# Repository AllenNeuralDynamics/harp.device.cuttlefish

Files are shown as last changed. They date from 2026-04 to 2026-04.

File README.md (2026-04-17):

An 8-channel TTL input-or-output device with programmable square wave output

## Features
* 8x TTL input or output, configurable.
* Direct PC control of IO Pins:
  * set pins configured as output to either HIGH (5V) or LOW (0V)
  * read the state of pins configured as inputs as either HIGH (~5V) or LOW (~0V) at TTL logic levels.
* Programmable square wave generation with many configurable settings:
  * PWM Frequency range: from 0.01Hz to 2KHz
  * Duty Cycle
  * Offset
  * number of pulses (or infinite)
* Input Capture. Configure pins as inputs to detect
  * rising edges (up to 500Hz)
  * falling edges (up to 500Hz)
  * both! (up to 500hz)
* Harp-protocol compliant (serial num: 0x057B).
* Bonus: "passthrough buffer mode." External 3.3V and 5V CMOS devices can use this device as an octal buffer with external pins.

> [!NOTE]
> This board produces digital outputs and measures digital inputs only! For producing high fidelity _analog_ outputs, refer to the [harp.device.quac](https://github.com/AllenNeuralDynamics/harp.device.quad-dac) device.

## Extra Features
* 6-24VDC input (2.1 x 5.5mm barrel jack, positive center)
* reverse polarity protection
* soft start
* isolated USB to avoid forming ground loops with the PC.

## PWM Waveform Setup
Each IO pin is capable of producing a PWM output. Here are the settings available:
* _offset_us_: how long (in microseconds) the output should remain LOW before switching the output HIGH in one period.
* _on_duration_us_: how long (in microseconds) the output should remain HIGH in one period.
* _off_duration_us_: how long (in microseconds) the output should remain LOW in one period.
* _cycles_: how many pulses to produce or zero for infinite pulses until disabled.
* _invert_: whether the output should be inverted (on-time refers to the output being LOW instead).

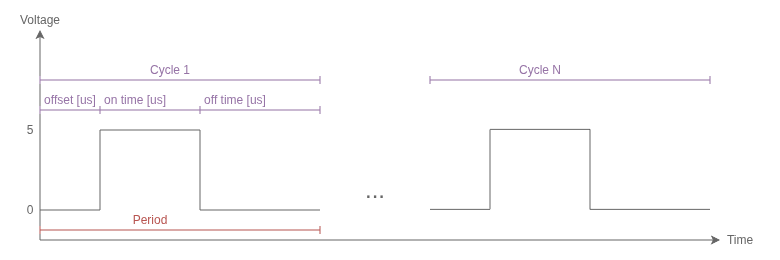
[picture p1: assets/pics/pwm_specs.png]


> [!NOTE]
> Although multiple PWM channels can be set to different settings and produce outputs concurrently, all PWM outputs must be started at the same time.

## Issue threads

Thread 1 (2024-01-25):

Consider alternate scheduling approaches

Poofjunior, 2024-01-25:
As implemented, this setup relies on timing from the Pico's alarm-based timer interrupt, called through the SDK's high-level interface. Currently, this implementation should be fine for frequencies up to 2 KHz but starts to show jitter around 50us.

Alternate approaches to alarm-based interrupts may include:
* using the second core
* using a DMA to PIO scheme where the PIO counts down to the next gpio action
* putting tight code in RAM.

Poofjunior, 2024-01-25:
Other insights:
* Fetching code (function calls) from flash has significant overhead. But it looks like running the ISR from ram has significant benefits ([link](https://forums.raspberrypi.com/viewtopic.php?t=338088))
* It may be possible to move the entire object to ram with `__not_in_flash()` ([link](https://forums.raspberrypi.com/viewtopic.php?t=321002))
* or just move the whole program to ram at the start. ([link](https://forums.raspberrypi.com/viewtopic.php?t=300974))

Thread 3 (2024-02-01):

Move scheduler to core1

Poofjunior, 2024-02-01:
With a tight update loop, we can create waveforms that update every 10 microseconds. But juggling Harp tasks slows down the main loop just enough that we can only update every 100 microseconds or so.

Putting the main loop on its own core and configuring it by sending pwm task parameters through a queue solves this problem.

Poofjunior, 2024-02-01:
done.

Closed 2024-02-01.

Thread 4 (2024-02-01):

Consume an additional alarm

Poofjunior, 2024-02-01:
We have an edge case where we are near an inexact beat frequency where the schedule can't be updated fast enough because two task state changes happen to closely in time. (This is not an issue for exact simultaneous events since we deliberately handle that case.)

The solution would be to be able to call update twice in advance before this inexact "beat frequency" event happened. This would require consuming another alarm to schedule another gpio port state event.

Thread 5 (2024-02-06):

Consider FixedPoint implementation

Poofjunior, 2024-02-06:
The current version of AccelStepper assumes floating point data types, whereas the [primary source](https://www.embedded.com/generate-stepper-motor-speed-profiles-in-real-time/) for this algorithm uses a FixedPoint implementation.

One modest optimization to speed up the main loop would be to rewrite the step computation loop to use FixedPoint in the range of speeds that we want.

* [Fixed Point data type  Reference](https://people.ece.cornell.edu/land/courses/ece4760/PIC32/index_fixed_point.html)

Closed 2024-02-13.

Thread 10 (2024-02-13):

SW Trigger should trigger the schedule immediately

Poofjunior, 2024-02-13:
After the device receives a software trigger command, there is a 1[ms] delay before the schedule starts.

This is an implementation quirk related to how scheduled times are computed. Fixing it would require local PWMTasks to track their interval rather than their absolute scheduled time.

Poofjunior, 2024-08-30:
Fixed in main.
Schedule is now pre-sorted on arrival, which saves the time needed to sort when issuing a software start such that we can start immediately.

Closed 2024-08-30.

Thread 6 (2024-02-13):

Detect if device is in passthrough mode

Poofjunior, 2024-02-13:
The schematic dedicates a GPIO pin to indicate whether the TTL connections are in passthrough mode (i.e: controlled by the external pins) or software mode (i.e: controlled by Harp).

We need to be able to detect the external state of the board and indicate it via a Harp register or event.

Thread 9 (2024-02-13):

Schedule should have the option of referencing Harp Time

Poofjunior, 2024-02-13:
Currently, the schedule computes future task changes based on the local time. It would be valuable to configure the schedule to run off of Harp time instead of local time if we care more about periodic events happening on a synchronized global time reference rather than intervals. (i.e: absolute times more important than relative times). This feature would also guarantee that multiple cuTTLfish boards could trigger synchronously in a way where they never drift from each other.

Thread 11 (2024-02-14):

Device should throw an error if it cannot satisfy schedule

Poofjunior, 2024-02-14:
Currently, core1 locks up when we cannot satisfy the current schedule timing. Instead, we should throw an error detectable by harp

We could implement this as a "weak" friend function in the cpp file that we can override in core1_main.

Poofjunior, 2024-02-15:
This is now implemented as a weak function that can be overwritten elsewhere.

https://github.com/AllenNeuralDynamics/harp.device.cuttlefish/blob/main/firmware/src/pwm_scheduler.cpp#L130

Custom implementation in main:
https://github.com/AllenNeuralDynamics/harp.device.cuttlefish/blob/main/firmware/src/core1_main.cpp#L16

Closed 2024-02-15.

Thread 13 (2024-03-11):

Desired Register Set

Poofjunior, 2024-03-11:
````c++
#pragma pack(push, 1)
struct app_regs_t
{
    volatile uint8_t port_dir; // 1 = output; 0 = input.
    volatile uint8_t port_raw; // current gpio state. Readable and writeable.
    volatile uint8_t pwm_task[sizeof(pwm_task_specs_t)]; // {offset_us (U32),
                                                         //  start_time_us (U32),
                                                         //  stop_time_us (U32),
                                                         //  port_mask (U8),
                                                         //  cycles (U32),
                                                         //  invert (U8)}
                                                         // This register reads
                                                         // all zeros.
    volatile uint8_t arm_ext_trigger; // which port pins (configured as
                                      // inputs) cause the schedule to
                                      // trigger.
                                      // Arm a hardware trigger.
                                      // [0] = 1: TTL pin 0 starts the trigger.
                                      // [1] = 1: TTL pin 1 starts the trigger.
    volatile uint8_t ext_trigger_edge; // value of the gpio pin(s) that cause
                                       // the schedule to start. Example:
                                       // [0]: set external TTL pin 0 trigger
                                       //      type to rising edge (1) or
                                       //      falling edge (0).
                                       // [1]: set external TTL pin 1 trigger
                                       //      type to rising edge (1) or
                                       //      falling edge (0).
                                       // ...
                                       // Resets to rising edge.
    volatile uint8_t arm_ext_untrigger; //
    volatile uint8_t ext_untrigger_edge;  //
    volatile uint8_t sw_trigger;    // Writing nonzero value to this register
                                    // starts the schedule.
    volatile uint8_t sw_untrigger;
    volatile uint8_t schedule_ctrl; // Apply/read various settings. Reads as 0.
                                    // [0] : Stop and clear all configured
                                    //       pwm_tasks.
                                    // [1] : dump 1 event message per configured
                                    //       pwm task from the pwm_task register
                                    //       followed by a
                                    //       write message from this register.
                                    // [4:7]: number of configured tasks.
    // More app "registers" here.
};
#pragma pack(pop)

````

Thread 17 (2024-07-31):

`PortState` change event not implemented

bruno-f-cruz, 2024-07-31:
An Event should be emitted from the `PortState` register each time any of the lines changes. This doesn't seem to be currently implemented.

bruno-f-cruz, 2024-07-31:
After a few more tests it seems the state of the register is not even reflecting the state of the port if I continuously poll from it using periodic read messages.

Poofjunior, 2024-08-08:
Ok, the behavior of `port_state` is to send back an `EVENT` message whenever the state of the pins specified as *inputs* changes state.

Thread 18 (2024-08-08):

Fix Ext/USB IO silkscreen

Poofjunior, 2024-08-08:
**EXT I/O** and **USB I/O** silkscreen values are flipped.

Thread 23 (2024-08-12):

Consider Error Status Register

Poofjunior, 2024-08-12:
Some user-initiated actions will be prevented by `WRITE_ERROR`s, but it is still useful to capture the "status" or "error state" in a separate register for aspects of the device state that can persist or happen.

Example *status* bits:
* `SCHEDULE_IS_RUNNING`
* `DEVICE_IN_EXTERNAL_IO_MODE`

Example *error status* bits:
* `SCHEDULE_FAILED_WHILE_RUNNING`
* `DEVICE_IN_EXTERNAL_IO_MODE`

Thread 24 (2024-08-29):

Disabling Task Should Kill Port Output

Poofjunior, 2024-08-29:
Currently, disabling the task leaves the GPIO pins in their current state, which may be outputting a 1.

Upon disabling the task, we should either:
* reset these pins to inputs
* disable the output

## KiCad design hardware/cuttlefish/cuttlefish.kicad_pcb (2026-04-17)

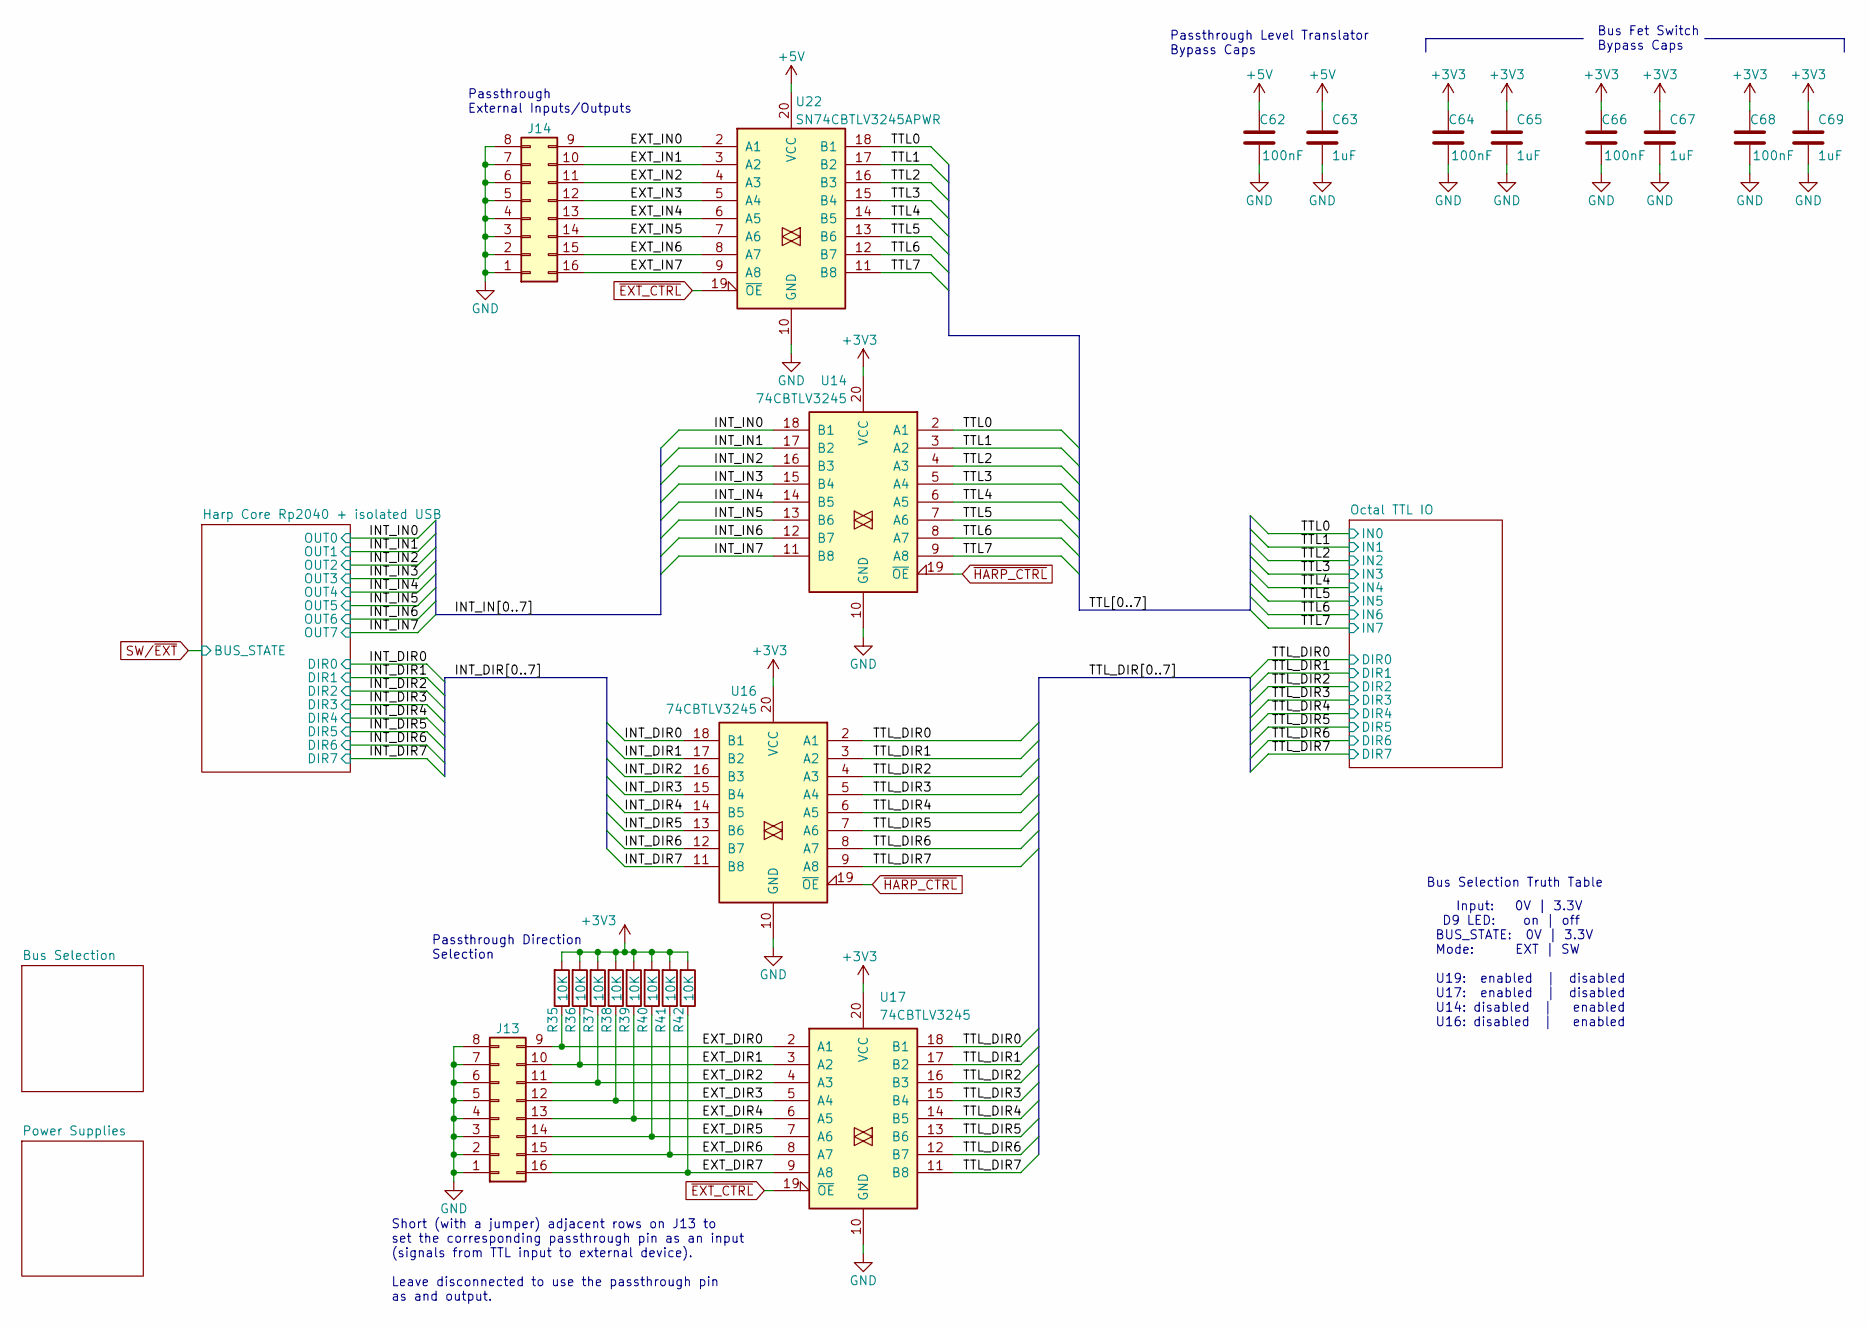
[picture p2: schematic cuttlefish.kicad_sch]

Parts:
C62, C64, C66, C68: 100nF; C_0402_1005Metric; Rated Voltage 50V; Tolerance 10%
C63, C65, C67, C69: 1uF; C_0402_1005Metric; Rated Voltage 35V
J13, J14: Conn_02x08_Counter_Clockwise; PinHeader_2x08_P2.54mm_Horizontal_SMD
R35, R36, R37, R38, R39, R40, R41, R42: 10K; R_0402_1005Metric
U14, U16, U17: 74CBTLV3245; TSSOP-20_4.4x6.5mm_P0.65mm
U22: SN74CBTLV3245APWR; TSSOP-20_4.4x6.5mm_P0.65mm

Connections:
+3V3: C64.2, C65.1, C66.2, C67.1, C68.2, C69.1, R35.2, R36.2, R37.2, R38.2, R39.2, R40.2, R41.2, R42.2, U14.20 (VCC), U16.20 (VCC), U17.20 (VCC); also elsewhere on the board
+5V: C62.2, C63.1, U22.20 (VCC); also elsewhere on the board
/EXT_DIR0: J13.9, R35.1, U17.2 (A1)
/EXT_DIR1: J13.10, R36.1, U17.3 (A2)
/EXT_DIR2: J13.11, R37.1, U17.4 (A3)
/EXT_DIR3: J13.12, R38.1, U17.5 (A4)
/EXT_DIR4: J13.13, R39.1, U17.6 (A5)
/EXT_DIR5: J13.14, R40.1, U17.7 (A6)
/EXT_DIR6: J13.15, R41.1, U17.8 (A7)
/EXT_DIR7: J13.16, R42.1, U17.9 (A8)
/EXT_IN0: J14.9, U22.2 (A1)
/EXT_IN1: J14.10, U22.3 (A2)
/EXT_IN2: J14.11, U22.4 (A3)
/EXT_IN3: J14.12, U22.5 (A4)
/EXT_IN4: J14.13, U22.6 (A5)
/EXT_IN5: J14.14, U22.7 (A6)
/EXT_IN6: J14.15, U22.8 (A7)
/EXT_IN7: J14.16, U22.9 (A8)
/INT_DIR0: U16.18 (B1); also elsewhere on the board
/INT_DIR1: U16.17 (B2); also elsewhere on the board
/INT_DIR2: U16.16 (B3); also elsewhere on the board
/INT_DIR3: U16.15 (B4); also elsewhere on the board
/INT_DIR4: U16.14 (B5); also elsewhere on the board
/INT_DIR5: U16.13 (B6); also elsewhere on the board
/INT_DIR6: U16.12 (B7); also elsewhere on the board
/INT_DIR7: U16.11 (B8); also elsewhere on the board
/INT_IN0: U14.18 (B1); also elsewhere on the board
/INT_IN1: U14.17 (B2); also elsewhere on the board
/INT_IN2: U14.16 (B3); also elsewhere on the board
/INT_IN3: U14.15 (B4); also elsewhere on the board
/INT_IN4: U14.14 (B5); also elsewhere on the board
/INT_IN5: U14.13 (B6); also elsewhere on the board
/INT_IN6: U14.12 (B7); also elsewhere on the board
/INT_IN7: U14.11 (B8); also elsewhere on the board
/TTL0: U14.2 (A1), U22.18 (B1); also elsewhere on the board
/TTL1: U14.3 (A2), U22.17 (B2); also elsewhere on the board
/TTL2: U14.4 (A3), U22.16 (B3); also elsewhere on the board
/TTL3: U14.5 (A4), U22.15 (B4); also elsewhere on the board
/TTL4: U14.6 (A5), U22.14 (B5); also elsewhere on the board
/TTL5: U14.7 (A6), U22.13 (B6); also elsewhere on the board
/TTL6: U14.8 (A7), U22.12 (B7); also elsewhere on the board
/TTL7: U14.9 (A8), U22.11 (B8); also elsewhere on the board
/TTL_DIR0: U16.2 (A1), U17.18 (B1); also elsewhere on the board
/TTL_DIR1: U16.3 (A2), U17.17 (B2); also elsewhere on the board
/TTL_DIR2: U16.4 (A3), U17.16 (B3); also elsewhere on the board
/TTL_DIR3: U16.5 (A4), U17.15 (B4); also elsewhere on the board
/TTL_DIR4: U16.6 (A5), U17.14 (B5); also elsewhere on the board
/TTL_DIR5: U16.7 (A6), U17.13 (B6); also elsewhere on the board
/TTL_DIR6: U16.8 (A7), U17.12 (B7); also elsewhere on the board
/TTL_DIR7: U16.9 (A8), U17.11 (B8); also elsewhere on the board
GND: C62.1, C63.2, C64.1, C65.2, C66.1, C67.2, C68.1, C69.2, J13.1, J13.2, J13.3, J13.4, J13.5, J13.6, J13.7, J13.8, J14.1, J14.2, J14.3, J14.4, J14.5, J14.6, J14.7, J14.8, U14.10 (GND), U16.10 (GND), U17.10 (GND), U22.10 (GND); also elsewhere on the board
~EXT_CTRL: U17.19 (~OE), U22.19 (~OE); also elsewhere on the board
~HARP_CTRL: U14.19 (~OE), U16.19 (~OE); also elsewhere on the board

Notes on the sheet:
Passthrough External Inputs/Outputs
Input: 0V | 3.3V D9 LED: on | off BUS_STATE: 0V | 3.3V Mode: EXT | SW U19: enabled | disabled U17: enabled | disabled U14: disabled | enabled U16: disabled | enabled
Passthrough Direction Selection
Bus Fet Switch Bypass Caps
Short (with a jumper) adjacent rows on J13 to set the corresponding passthrough pin as an input (signals from TTL input to external device). Leave disconnected to use the passthrough pin as and output.
Passthrough Level Translator Bypass Caps
Bus Selection Truth Table

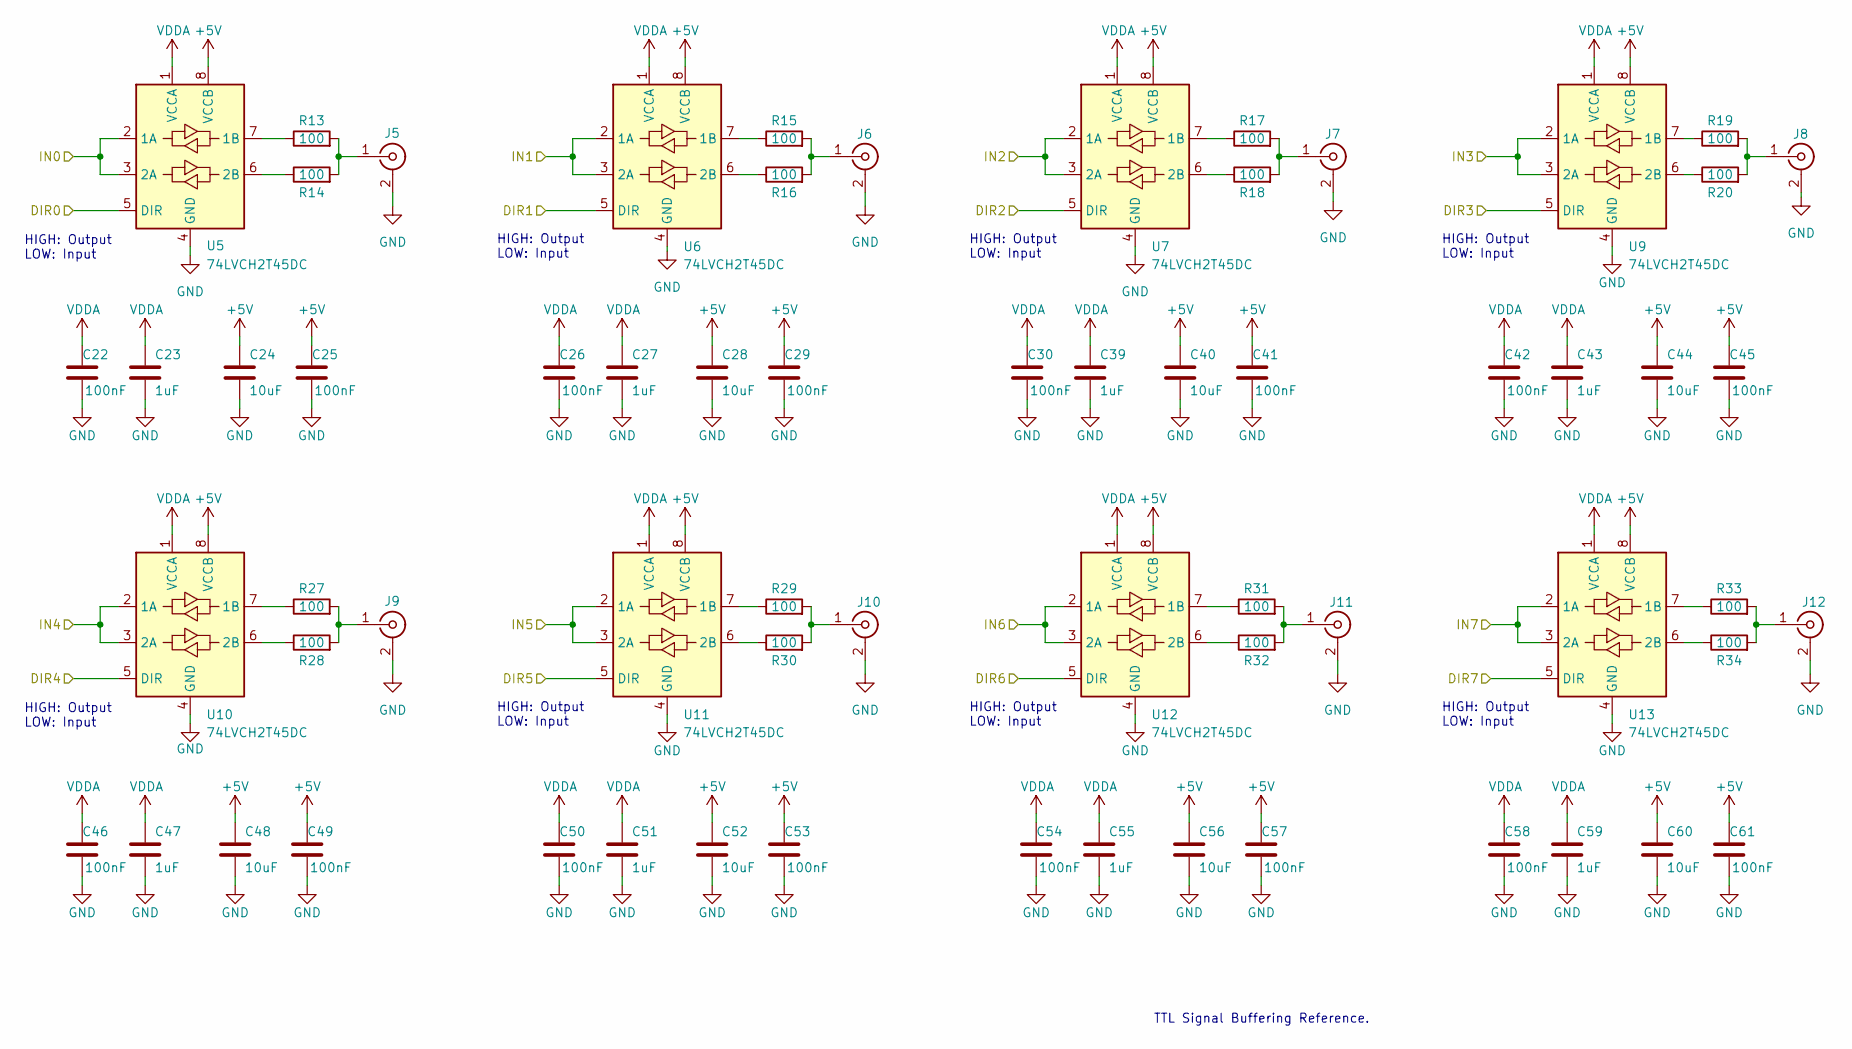
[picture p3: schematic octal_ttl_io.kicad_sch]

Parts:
C22, C25, C26, C29, C30, C41, C42, C45, C46, C49, C50, C53, C54, C57, C58, C61: 100nF; C_0402_1005Metric; Rated Voltage 50V; Tolerance 10%
C23, C27, C39, C43, C47, C51, C55, C59: 1uF; C_0402_1005Metric; Rated Voltage 35V
C24, C28, C40, C44, C48, C52, C56, C60: 10uF; C_0805_2012Metric; Rated Voltage 25V
J5, J6, J7, J8, J9, J10, J11, J12: Conn_Coaxial; BNC_AmphenolRF_031-5329-52RFX_Vertical
R13, R14, R15, R16, R17, R18, R19, R20, R27, R28, R29, R30, R31, R32, R33, R34: 100; R_0402_1005Metric; Tolerance 1%
U5, U6, U7, U9, U10, U11, U12, U13: 74LVCH2T45DC; VSSOP-8_2.3x2mm_P0.5mm_TexasInstruments

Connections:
+5V: C24.1, C25.2, C28.1, C29.2, C40.1, C41.2, C44.1, C45.2, C48.1, C49.2, C52.1, C53.2, C56.1, C57.2, C60.1, C61.2, U5.8 (VCCB), U6.8 (VCCB), U7.8 (VCCB), U9.8 (VCCB), U10.8 (VCCB), U11.8 (VCCB), U12.8 (VCCB), U13.8 (VCCB); also elsewhere on the board
/TTL0: U5.2 (1A), U5.3 (2A); also elsewhere on the board
/TTL1: U6.2 (1A), U6.3 (2A); also elsewhere on the board
/TTL2: U7.2 (1A), U7.3 (2A); also elsewhere on the board
/TTL3: U9.2 (1A), U9.3 (2A); also elsewhere on the board
/TTL4: U10.2 (1A), U10.3 (2A); also elsewhere on the board
/TTL5: U11.2 (1A), U11.3 (2A); also elsewhere on the board
/TTL6: U12.2 (1A), U12.3 (2A); also elsewhere on the board
/TTL7: U13.2 (1A), U13.3 (2A); also elsewhere on the board
/TTL_DIR0: U5.5 (DIR); also elsewhere on the board
/TTL_DIR1: U6.5 (DIR); also elsewhere on the board
/TTL_DIR2: U7.5 (DIR); also elsewhere on the board
/TTL_DIR3: U9.5 (DIR); also elsewhere on the board
/TTL_DIR4: U10.5 (DIR); also elsewhere on the board
/TTL_DIR5: U11.5 (DIR); also elsewhere on the board
/TTL_DIR6: U12.5 (DIR); also elsewhere on the board
/TTL_DIR7: U13.5 (DIR); also elsewhere on the board
GND: C22.1, C23.2, C24.2, C25.1, C26.1, C27.2, C28.2, C29.1, C30.1, C39.2, C40.2, C41.1, C42.1, C43.2, C44.2, C45.1, C46.1, C47.2, C48.2, C49.1, C50.1, C51.2, C52.2, C53.1, C54.1, C55.2, C56.2, C57.1, C58.1, C59.2, C60.2, C61.1, J5.2 (Ext), J6.2 (Ext), J7.2 (Ext), J8.2 (Ext), J9.2 (Ext), J10.2 (Ext), J11.2 (Ext), J12.2 (Ext), U5.4 (GND), U6.4 (GND), U7.4 (GND), U9.4 (GND), U10.4 (GND), U11.4 (GND), U12.4 (GND), U13.4 (GND); also elsewhere on the board
unnamed: J5.1 (In), R13.2, R14.2
unnamed: J6.1 (In), R15.2, R16.2
unnamed: J7.1 (In), R17.2, R18.2
unnamed: J8.1 (In), R19.2, R20.2
unnamed: J9.1 (In), R27.2, R28.2
unnamed: J10.1 (In), R29.2, R30.2
unnamed: J11.1 (In), R31.2, R32.2
unnamed: J12.1 (In), R33.2, R34.2
unnamed: R13.1, U5.7 (1B)
unnamed: R14.1, U5.6 (2B)
unnamed: R15.1, U6.7 (1B)
unnamed: R16.1, U6.6 (2B)
unnamed: R17.1, U7.7 (1B)
unnamed: R18.1, U7.6 (2B)
unnamed: R19.1, U9.7 (1B)
unnamed: R20.1, U9.6 (2B)
unnamed: R27.1, U10.7 (1B)
unnamed: R28.1, U10.6 (2B)
unnamed: R29.1, U11.7 (1B)
unnamed: R30.1, U11.6 (2B)
unnamed: R31.1, U12.7 (1B)
unnamed: R32.1, U12.6 (2B)
unnamed: R33.1, U13.7 (1B)
unnamed: R34.1, U13.6 (2B)
VDDA: C22.2, C23.1, C26.2, C27.1, C30.2, C39.1, C42.2, C43.1, C46.2, C47.1, C50.2, C51.1, C54.2, C55.1, C58.2, C59.1, U5.1 (VCCA), U6.1 (VCCA), U7.1 (VCCA), U9.1 (VCCA), U10.1 (VCCA), U11.1 (VCCA), U12.1 (VCCA), U13.1 (VCCA); also elsewhere on the board

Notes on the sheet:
HIGH: Output LOW: Input
TTL Signal Buffering Reference.

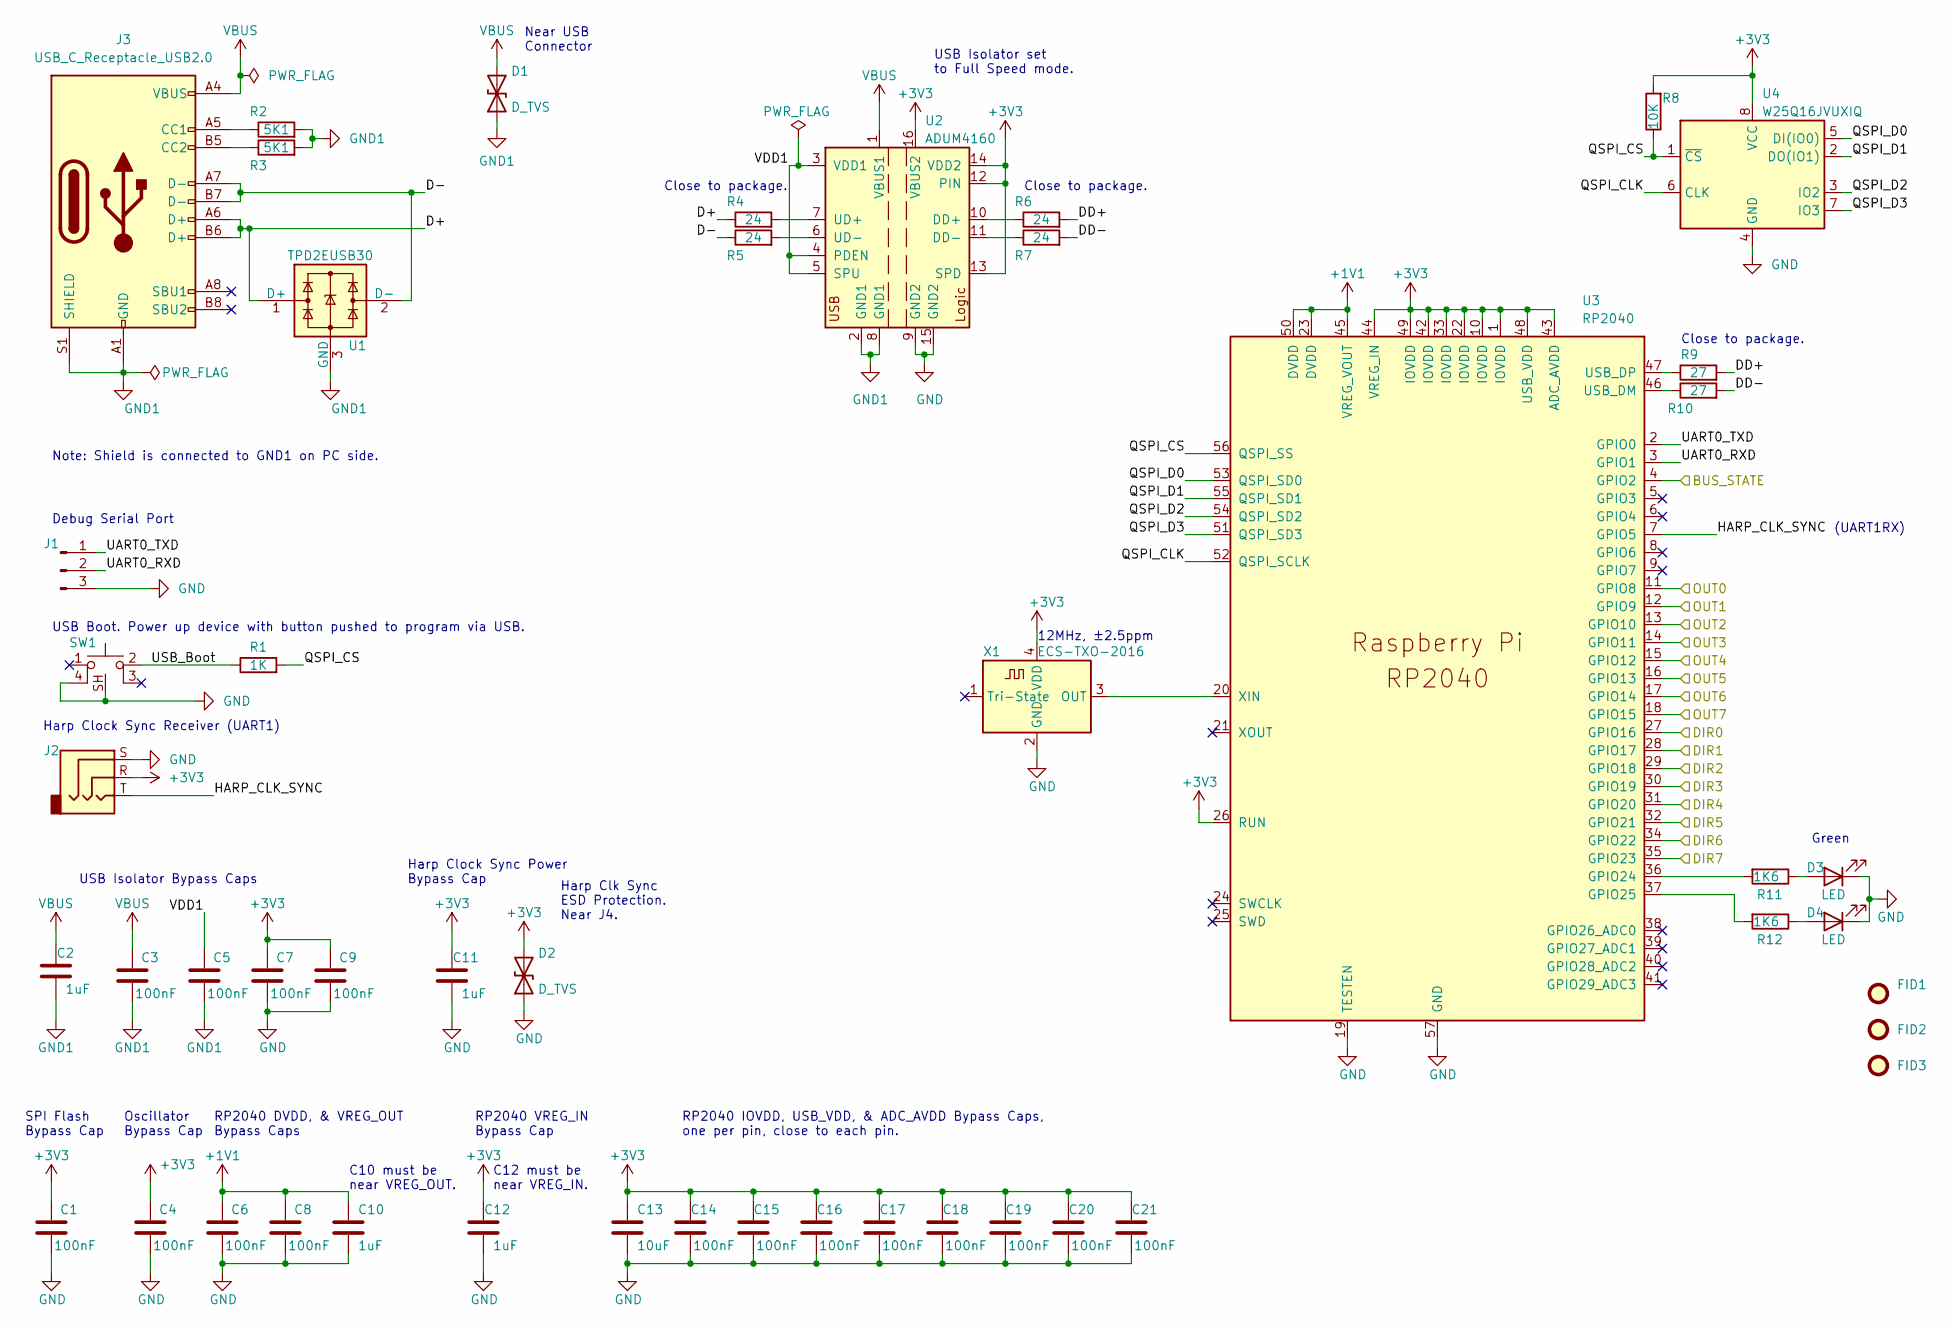
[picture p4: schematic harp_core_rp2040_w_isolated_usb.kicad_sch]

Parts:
C1, C3, C4, C5, C6, C7, C8, C9, C14, C15, C16, C17, C18, C19, C20, C21: 100nF; C_0402_1005Metric; Rated Voltage 50V; Tolerance 10%
C2, C10, C11, C12: 1uF; C_0402_1005Metric; Rated Voltage 35V
C13: 10uF; C_0805_2012Metric; Rated Voltage 25V
D1, D2: D_TVS; D_0402_1005Metric
D3, D4: LED; LED_0603_1608Metric
FID1, FID2, FID3: Fiducial; Fiducial_0.5mm_Mask1mm
J1: Conn_01x03_Male; PinHeader_1x03_P2.54mm_Vertical
J2: AudioJack3; Jack_3.5mm_CUI_SJ-3523-SMT_Horizontal
J3: USB_C_Receptacle_USB2.0; USB_C_Receptacle_JAE_DX07S016JA1R1500
R1: 1K; R_0402_1005Metric; Tolerance 1%
R2, R3: 5K1; R_0402_1005Metric; Tolerance 1%
R4, R5, R6, R7: 24; R_0402_1005Metric; Tolerance 1%
R8: 10K; R_0402_1005Metric
R9, R10: 27; R_0402_1005Metric; Tolerance 1%
R11, R12: 1K6; R_0402_1005Metric
SW1: SW_Push_1P1T-SH_NO_Vertical_Wuerth_WS-TASV
U1: TPD2EUSB30; Texas_DRT-3
U2: ADUM4160; SOIC-16W_7.5x10.3mm_P1.27mm
U3: RP2040; RP2040-QFN-56
U4: W25Q16JVUXIQ; Winbond-8USON-2x3mm
X1: ECS-TXO-2016; Crystal_SMD_2016-4Pin_2.0x1.6mm; Tolerance ±2.5ppm

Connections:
+1V1: C6.2, C8.2, C10.1, U3.23 (DVDD), U3.45 (VREG_VOUT), U3.50 (DVDD)
+3V3: C1.2, C4.2, C7.2, C9.2, C11.1, C12.1, C13.1, C14.2, C15.2, C16.2, C17.2, C18.2, C19.2, C20.2, C21.2, D2.2 (A2), J2.R, R8.2, U2.12 (PIN), U2.13 (SPD), U2.14 (VDD2), U2.16 (VBUS2), U3.1 (IOVDD), U3.10 (IOVDD), U3.22 (IOVDD), U3.26 (RUN), U3.33 (IOVDD), U3.42 (IOVDD), U3.43 (ADC_AVDD), U3.44 (VREG_IN), U3.48 (USB_VDD), U3.49 (IOVDD), U4.8 (VCC), X1.4 (VDD); also elsewhere on the board
/Harp Core Rp2040 + isolated USB/D+: J3.A6 (D+), J3.B6 (D+), R4.1, U1.1 (D+)
/Harp Core Rp2040 + isolated USB/D-: J3.A7 (D-), J3.B7 (D-), R5.1, U1.2 (D-)
/Harp Core Rp2040 + isolated USB/DD+: R6.2, R9.2
/Harp Core Rp2040 + isolated USB/DD-: R7.2, R10.2
/Harp Core Rp2040 + isolated USB/HARP_CLK_SYNC: J2.T, U3.7 (GPIO5)
/Harp Core Rp2040 + isolated USB/QSPI_CLK: U3.52 (QSPI_SCLK), U4.6 (CLK)
/Harp Core Rp2040 + isolated USB/QSPI_CS: R1.2, R8.1, U3.56 (QSPI_SS), U4.1 (~CS)
/Harp Core Rp2040 + isolated USB/QSPI_D0: U3.53 (QSPI_SD0), U4.5 (DI(IO0))
/Harp Core Rp2040 + isolated USB/QSPI_D1: U3.55 (QSPI_SD1), U4.2 (DO(IO1))
/Harp Core Rp2040 + isolated USB/QSPI_D2: U3.54 (QSPI_SD2), U4.3 (IO2)
/Harp Core Rp2040 + isolated USB/QSPI_D3: U3.51 (QSPI_SD3), U4.7 (IO3)
/Harp Core Rp2040 + isolated USB/UART0_RXD: J1.2, U3.3 (GPIO1)
/Harp Core Rp2040 + isolated USB/UART0_TXD: J1.1, U3.2 (GPIO0)
/Harp Core Rp2040 + isolated USB/USB_Boot: R1.1, SW1.2
/Harp Core Rp2040 + isolated USB/VDD1: C5.2, U2.3 (VDD1), U2.4 (PDEN), U2.5 (SPU)
/INT_DIR0: U3.27 (GPIO16); also elsewhere on the board
/INT_DIR1: U3.28 (GPIO17); also elsewhere on the board
/INT_DIR2: U3.29 (GPIO18); also elsewhere on the board
/INT_DIR3: U3.30 (GPIO19); also elsewhere on the board
/INT_DIR4: U3.31 (GPIO20); also elsewhere on the board
/INT_DIR5: U3.32 (GPIO21); also elsewhere on the board
/INT_DIR6: U3.34 (GPIO22); also elsewhere on the board
/INT_DIR7: U3.35 (GPIO23); also elsewhere on the board
/INT_IN0: U3.11 (GPIO8); also elsewhere on the board
/INT_IN1: U3.12 (GPIO9); also elsewhere on the board
/INT_IN2: U3.13 (GPIO10); also elsewhere on the board
/INT_IN3: U3.14 (GPIO11); also elsewhere on the board
/INT_IN4: U3.15 (GPIO12); also elsewhere on the board
/INT_IN5: U3.16 (GPIO13); also elsewhere on the board
/INT_IN6: U3.17 (GPIO14); also elsewhere on the board
/INT_IN7: U3.18 (GPIO15); also elsewhere on the board
GND: C1.1, C4.1, C6.1, C7.1, C8.1, C9.1, C10.2, C11.2, C12.2, C13.2, C14.1, C15.1, C16.1, C17.1, C18.1, C19.1, C20.1, C21.1, D2.1 (A1), D3.1 (K), D4.1 (K), J1.3, J2.S, SW1.4, SW1.SH, U2.9 (GND2), U2.15 (GND2), U3.19 (TESTEN), U3.57 (GND), U4.4 (GND), X1.2 (GND); also elsewhere on the board
GND1: C2.2, C3.1, C5.1, D1.1 (A1), J3.A1 (GND), J3.A12 (GND), J3.B1 (GND), J3.B12 (GND), J3.S1 (SHIELD), R2.2, R3.2, U1.3 (GND), U2.2 (GND1), U2.8 (GND1)
unnamed: D3.2 (A), R11.1
unnamed: D4.2 (A), R12.1
unnamed: J3.A5 (CC1), R2.1
unnamed: J3.B5 (CC2), R3.1
unnamed: R6.1, U2.10 (DD+)
unnamed: R7.1, U2.11 (DD-)
unnamed: R4.2, U2.7 (UD+)
unnamed: R5.2, U2.6 (UD-)
unnamed: R11.2, U3.36 (GPIO24)
unnamed: R12.2, U3.37 (GPIO25)
unnamed: R10.1, U3.46 (USB_DM)
unnamed: R9.1, U3.47 (USB_DP)
unnamed: U3.20 (XIN), X1.3 (OUT)
SW/~EXT: U3.4 (GPIO2); also elsewhere on the board
VBUS: C2.1, C3.2, D1.2 (A2), J3.A4 (VBUS), J3.A9 (VBUS), J3.B4 (VBUS), J3.B9 (VBUS), U2.1 (VBUS1)

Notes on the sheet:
USB Isolator Bypass Caps
Near USB Connector
Close to package.
Harp Clock Sync Power Bypass Cap
USB Isolator set to Full Speed mode.
12MHz, ±2.5ppm
Debug Serial Port
USB Boot. Power up device with button pushed to program via USB.
(UART1RX)
Harp Clock Sync Receiver (UART1)
Note: Shield is connected to GND1 on PC side.
RP2040 DVDD, & VREG_OUT Bypass Caps
RP2040 IOVDD, USB_VDD, & ADC_AVDD Bypass Caps, one per pin, close to each pin.
C10 must be near VREG_OUT.
RP2040 VREG_IN Bypass Cap
SPI Flash Bypass Cap
Harp Clk Sync ESD Protection. Near J4.
Oscillator Bypass Cap
C12 must be near VREG_IN.
Green

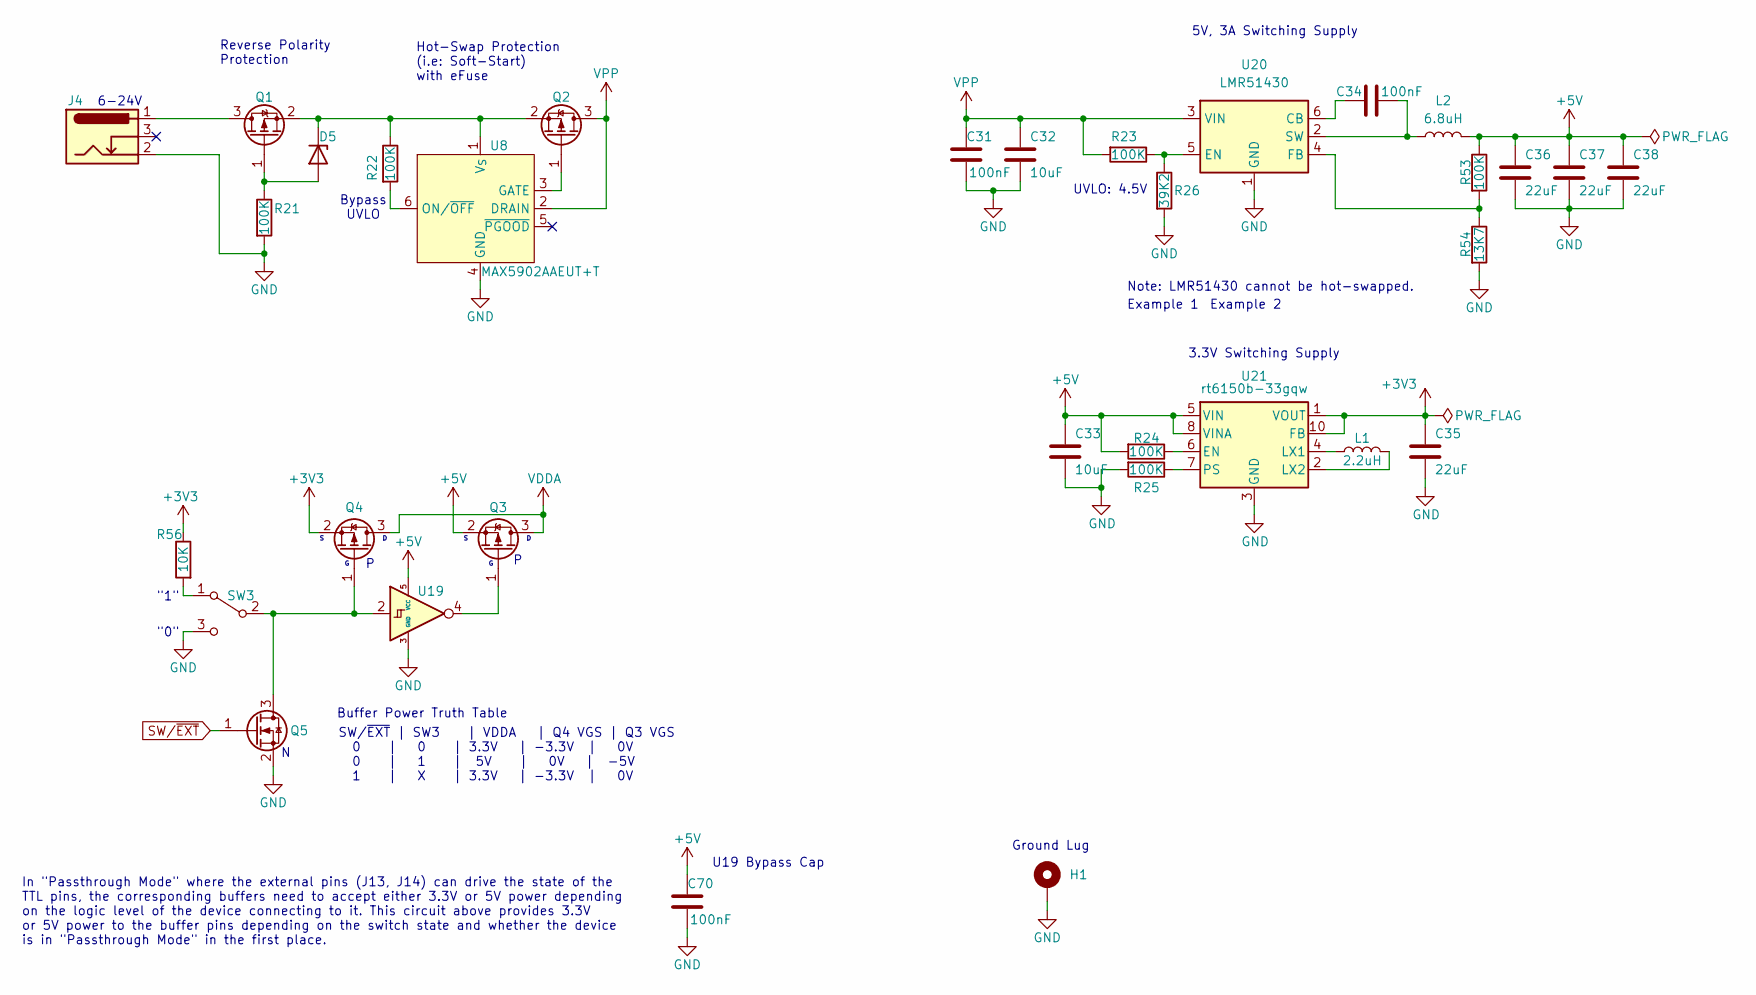
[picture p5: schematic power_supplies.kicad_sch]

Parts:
C31, C34, C70: 100nF; C_0402_1005Metric; Rated Voltage 50V; Tolerance 10%
C32, C33: 10uF; C_0805_2012Metric; Rated Voltage 25V
C35, C36, C37, C38: 22uF; C_0805_2012Metric; Rated Voltage 25V
D5: BZV55B15; D_MiniMELF
H1: MountingHole_Pad; Terminal_Keystone_779x_EdgeMount_Horizontal
J4: Barrel_Jack_Switch; BarrelJack_Same_Sky_PJ-102AH_Horizontal
L1: 2.2uH; L_0603_1608Metric
L2: 6.8uH; L_Bourns-SRP4030FA
Q1, Q2, Q3, Q4: Si2369DS; SOT-23
Q5: DMN2040U; SOT-23
R21, R22, R23, R24, R25, R53: 100K; R_0402_1005Metric; Tolerance 1%
R26: 39K2; R_0402_1005Metric; Tolerance 1%
R54: 13K7; R_0402_1005Metric; Tolerance 1%
R56: 10K; R_0402_1005Metric
SW3: SW_SPDT; SW_SPDT_CK-JS102011SAQN
U8: MAX5902AAEUT+T; SOT-23-6
U19: SN74LVC1G14DRL; SOT-553
U20: LMR51430; SOT-23-6
U21: rt6150b-33gqw; WDFN-10-1EP_2.5x2.5mm_P0.5_EP1.25x2.1mm

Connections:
+3V3: C35.1, Q4.2 (S), R56.1, U21.1 (VOUT), U21.10 (FB); also elsewhere on the board
+5V: C33.1, C36.1, C37.1, C38.1, C70.2, L2.2, Q3.2 (S), R24.2, R53.1, U19.5 (VCC), U21.5 (VIN), U21.8 (VINA); also elsewhere on the board
GND: C31.1, C32.2, C33.2, C35.2, C36.2, C37.2, C38.2, C70.1, H1.1, J4.2, Q5.2 (S), R21.2, R25.2, R26.2, R54.2, SW3.3 (C), U8.4 (GND), U19.3 (GND), U20.1 (GND), U21.3 (GND), U21.9 (GND), U21.11 (GND); also elsewhere on the board
unnamed: D5.2 (A), Q1.1 (G), R21.1
unnamed: D5.1 (K), Q1.2 (S), Q2.2 (S), R22.1, U8.1 (V_{S})
unnamed: J4.1, Q1.3 (D)
unnamed: Q2.1 (G), U8.3 (GATE)
unnamed: Q3.1 (G), U19.4
unnamed: Q4.1 (G), Q5.3 (D), SW3.2 (B), U19.2
unnamed: R56.2, SW3.1 (A)
unnamed: R22.2, U8.6 (ON/~OFF)
unnamed: C34.2, U20.6 (CB)
unnamed: R23.1, R26.1, U20.5 (EN)
unnamed: R53.2, R54.1, U20.4 (FB)
unnamed: C34.1, L2.1, U20.2 (SW)
unnamed: R24.1, U21.6 (EN)
unnamed: L1.1, U21.4 (LX1)
unnamed: L1.2, U21.2 (LX2)
unnamed: R25.1, U21.7 (PS)
SW/~EXT: Q5.1 (G); also elsewhere on the board
VDDA: Q3.3 (D), Q4.3 (D); also elsewhere on the board
VPP: C31.2, C32.1, Q2.3 (D), R23.2, U8.2 (DRAIN), U20.3 (VIN)

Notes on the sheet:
U19 Bypass Cap
Example 2
5V, 3A Switching Supply
"1"
"0"
Example 1
Bypass UVLO
Note: LMR51430 cannot be hot-swapped.
Buffer Power Truth Table
UVLO: 4.5V
Hot-Swap Protection (i.e: Soft-Start) with eFuse
6-24V
In "Passthrough Mode" where the external pins (J13, J14) can drive the state of the TTL pins, the corresponding buffers need to accept either 3.3V or 5V power depending on the logic level of the device connecting to it. This circuit above provides 3.3V or 5V power to the buffer pins depending on th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
SW/~{EXT} | SW3 | VDDA | Q4 VGS | Q3 VGS 0 | 0 | 3.3V | -3.3V | 0V 0 | 1 | 5V | 0V | -5V 1 | X | 3.3V | -3.3V | 0V
Ground Lug
3.3V Switching Supply
Reverse Polarity Protection

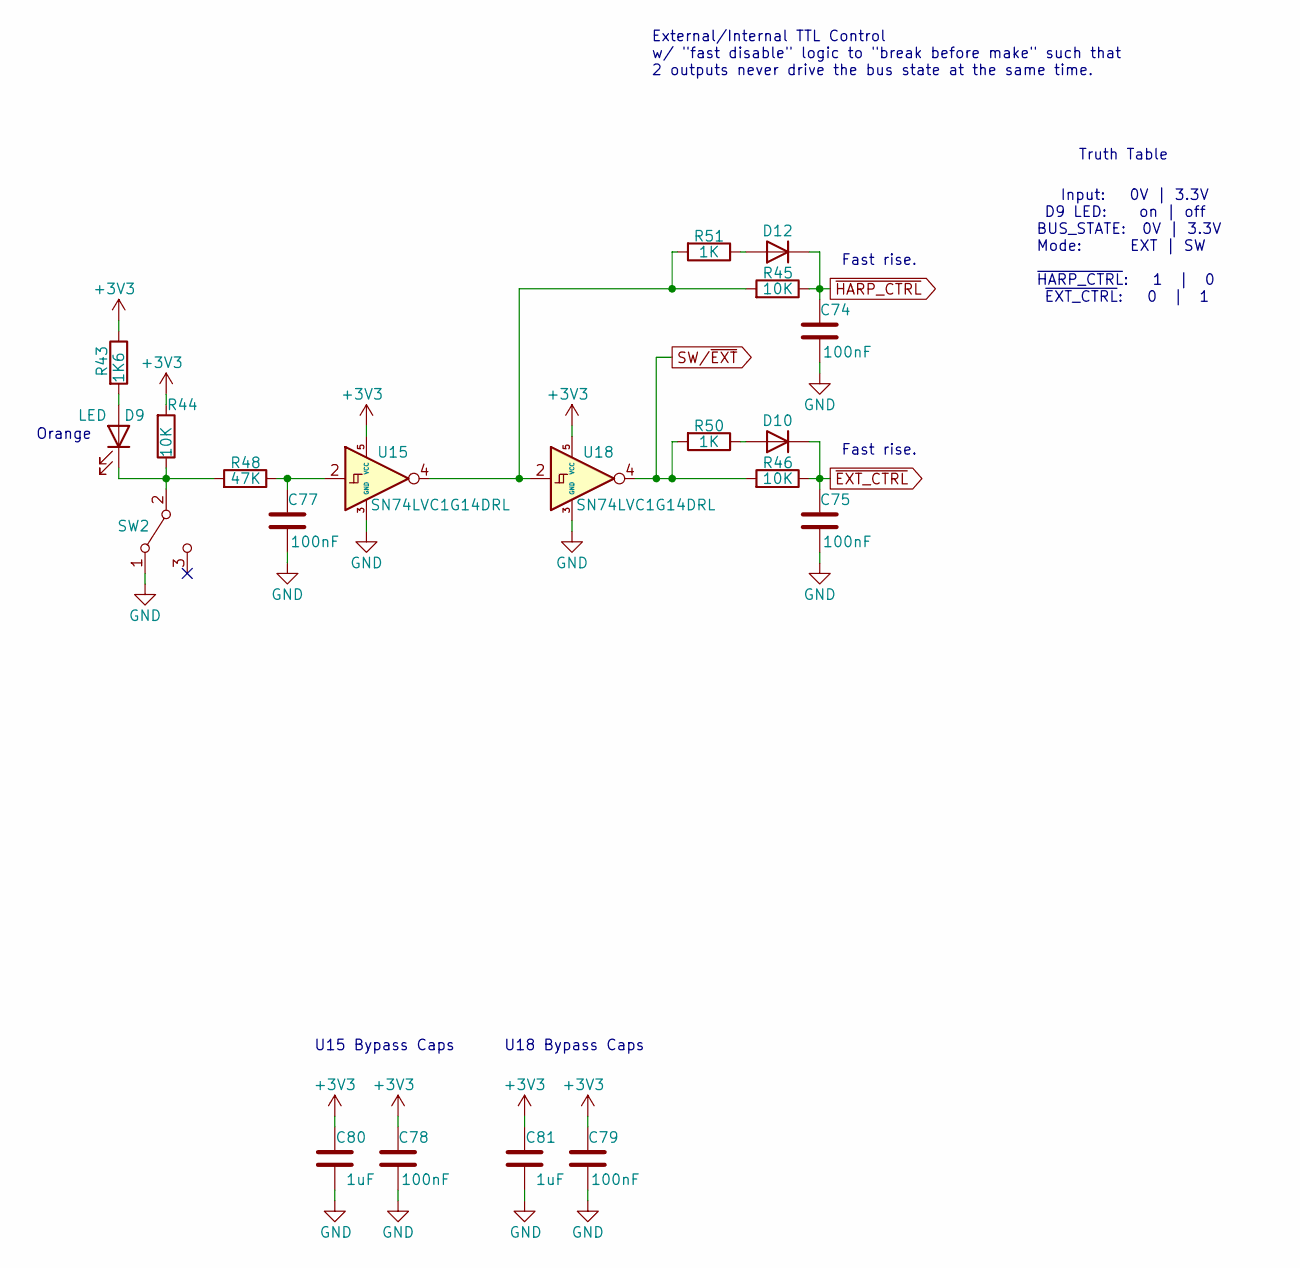
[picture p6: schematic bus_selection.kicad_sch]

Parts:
C74, C75, C77, C78, C79: 100nF; C_0402_1005Metric; Rated Voltage 50V; Tolerance 10%
C80, C81: 1uF; C_0402_1005Metric; Rated Voltage 35V
D9: LED; LED_0603_1608Metric
D10, D12: NSR05F40NXT5G; D_0402_1005Metric
R43: 1K6; R_0402_1005Metric
R44, R45, R46: 10K; R_0402_1005Metric
R48: 47K; R_0402_1005Metric; Tolerance 1%
R50, R51: 1K; R_0402_1005Metric; Tolerance 1%
SW2: SW_SPDT; SW_SPDT_CK-JS102011SAQN
U15, U18: SN74LVC1G14DRL; SOT-553

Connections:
+3V3: C78.2, C79.2, C80.1, C81.1, R43.1, R44.2, U15.5 (VCC), U18.5 (VCC); also elsewhere on the board
GND: C74.1, C75.1, C77.1, C78.1, C79.1, C80.2, C81.2, SW2.1 (A), U15.3 (GND), U18.3 (GND); also elsewhere on the board
unnamed: C77.2, R48.1, U15.2
unnamed: D9.2 (A), R43.2
unnamed: D9.1 (K), R44.1, R48.2, SW2.2 (B)
unnamed: D10.2 (A), R50.1
unnamed: D12.2 (A), R51.1
unnamed: R45.2, R51.2, U15.4, U18.2
SW/~EXT: R46.2, R50.2, U18.4; also elsewhere on the board
~EXT_CTRL: C75.2, D10.1 (K), R46.1; also elsewhere on the board
~HARP_CTRL: C74.2, D12.1 (K), R45.1; also elsewhere on the board

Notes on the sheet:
Truth Table
External/Internal TTL Control w/ "fast disable" logic to "break before make" such that 2 outputs never drive the bus state at the same time.
U18 Bypass Caps
Input: 0V | 3.3V D9 LED: on | off BUS_STATE: 0V | 3.3V Mode: EXT | SW ~{HARP_CTRL}: 1 | 0 ~{EXT_CTRL}: 0 | 1
U15 Bypass Caps
Fast rise.
Orange

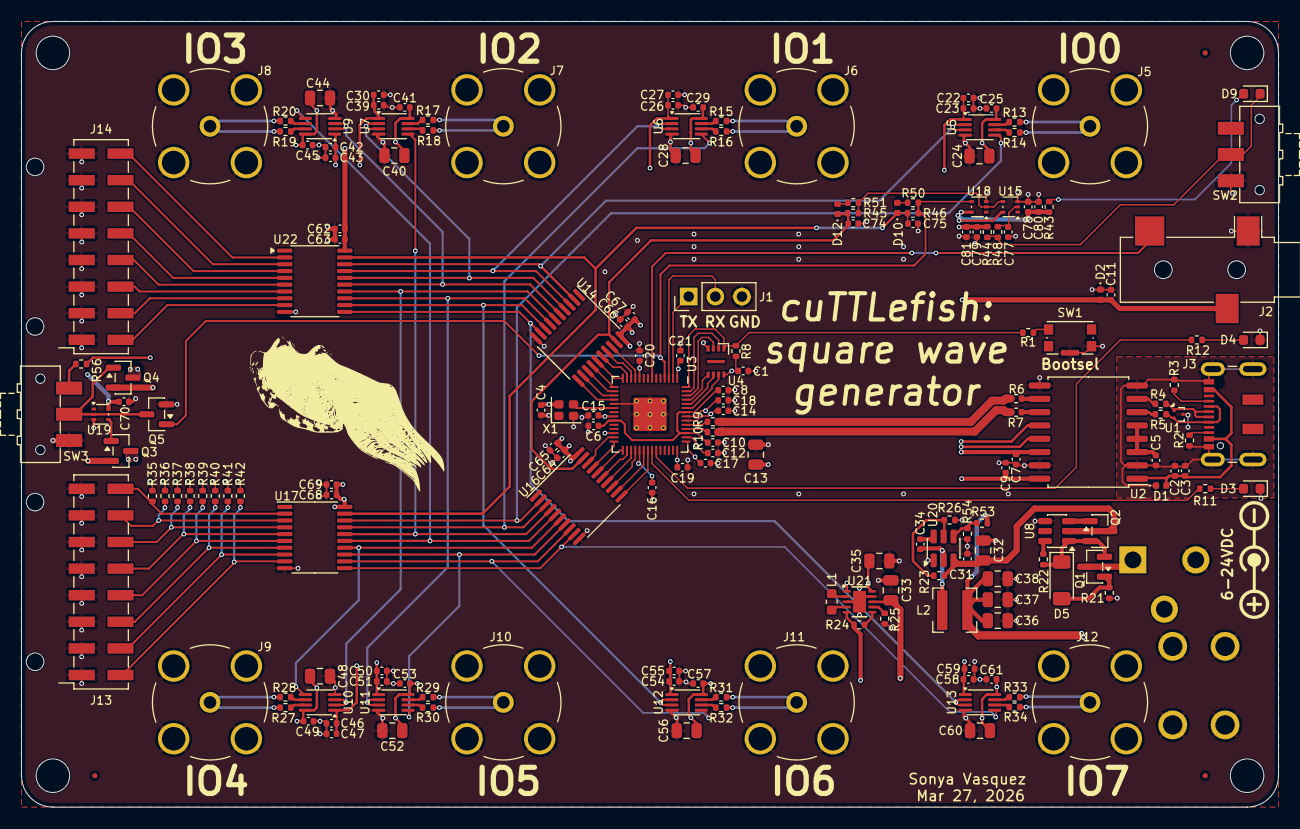
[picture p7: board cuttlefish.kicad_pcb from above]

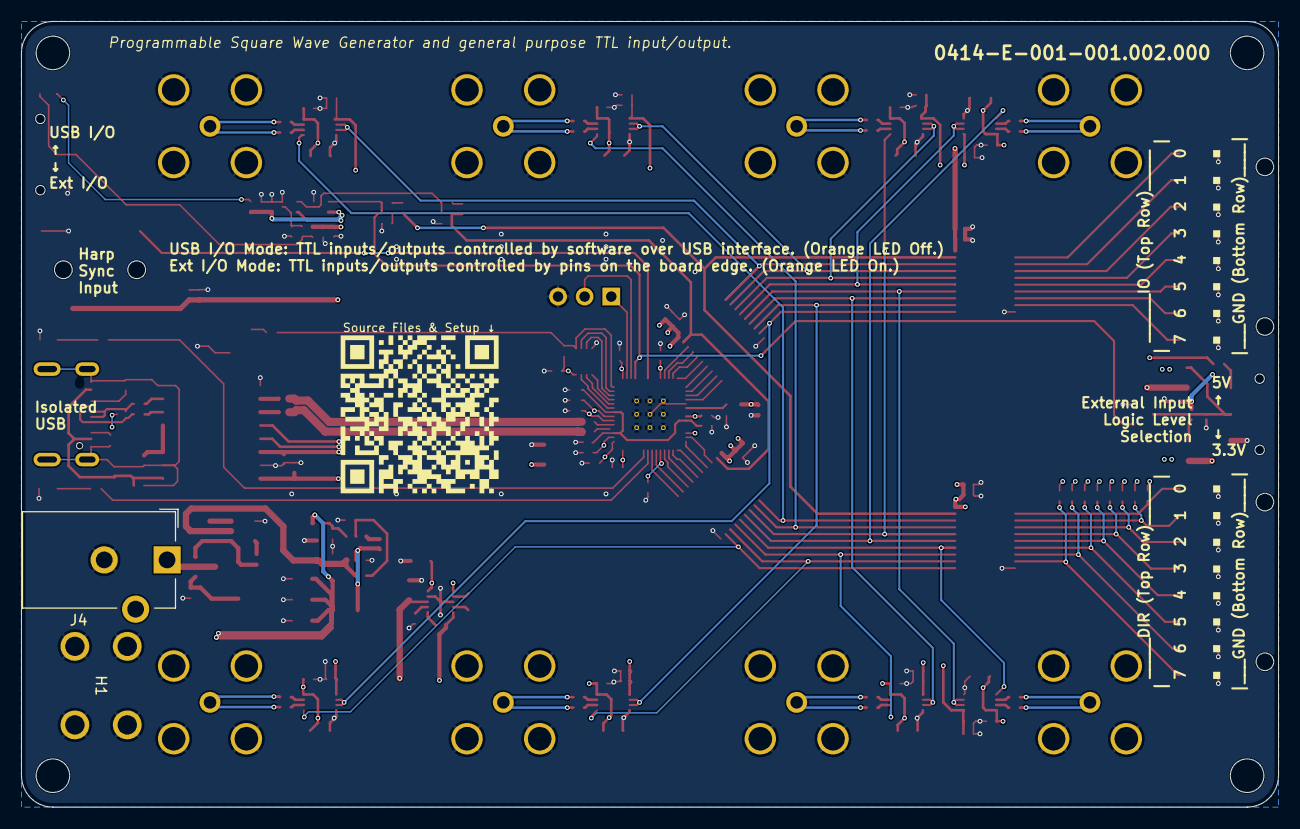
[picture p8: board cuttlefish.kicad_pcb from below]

Board: 4 copper layers, 120.0 x 75.0 mm, 189 parts (2 on the bottom side), 133 nets.

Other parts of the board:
G3: LOGO

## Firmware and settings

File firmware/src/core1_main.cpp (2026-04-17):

#include <core1_main.h>

__not_in_flash("core1_next_state") core1_state_t state;
__not_in_flash("schedule_failed") bool schedule_failed;
__not_in_flash("scheduler")PWMScheduler scheduler;


/// Do not call this func inside and outside an ISR context on either core.
inline uint64_t time_us_64_unsafe()
{
    uint64_t time = timer_hw->timelr; // Locks time_lr/hr until we read TIMEHR.
    return (uint64_t(timer_hw->timehr) << 32) | time;
}


// Override default behavior of this function defined weakly elsewhere.
void handle_missed_deadline()
{
    gpio_init(LED1);
    gpio_set_dir(LED1, 1); // output
    gpio_put(LED1, 1); // turn on auxilary LED.
    schedule_failed = true;
    // TODO: push an error message back to core0.
}


void sync_schedule()
{
    /// friend function to PWMScheduler and PWMTask.
    /// Should only be called before running the schedule.
    pwm_specs_core_msg_t settings;
    while (queue_try_remove(&pwm_settings_queue, &settings))
    {
        // If the pin is already assigned to a specific set of settings in the
        // schedule, update them. Otherwise, create a new PWMTask and
        // push it into the schedule.
        //
        // Note that since the schedule is presorted, we need to pop out
        // all tasks until we find the right one, update it, and then push
        // them all back--gross.
        bool updated_existing_task = false;
        etl::vector<std::reference_wrapper<PWMTask>, NUM_TTL_IOS> tmp_tasks;
        while (!scheduler.pq_.empty())
        {
            PWMTask& task = scheduler.pq_.top().get();
            if (task.pin_mask_ != (1u << settings.pin))
            {
                scheduler.pq_.pop();
                tmp_tasks.push_back(task);
                continue;
            }
            // Update existing task specs.
            task.delay_us_ = settings.specs.offset_us;
            task.on_time_us_ = settings.specs.on_duration_us;
            task.period_us_ = settings.specs.period_us();
            task.count_ = settings.specs.cycles;
            task.invert_ = bool(settings.specs.invert);
            updated_existing_task = true;
            break;
        }
        while (!tmp_tasks.empty())
        {
            PWMTask& task = tmp_tasks.back();
            scheduler.pq_.push(task);
            tmp_tasks.pop_back();
        }
        if (!updated_existing_task)
        {
            scheduler.schedule_pwm_task(settings.specs.offset_us,
                                        settings.specs.on_duration_us,
                                        settings.specs.period_us(),
                                        1u << settings.pin,
                                        settings.specs.cycles,
                                        bool(settings.specs.invert));
        }
    }
}


void __not_in_flash_func(run_task_loop)()
{
    using enum core1_state_t;

    core1_state_t next_state = state;
    pwm_specs_core_msg_t msg;

    //Get input from core0 control queue.
    pwm_ctrl_msg_t ctrl_msg;
    bool new_ctrl_msg = queue_try_remove(&core1_ctrl_queue, &ctrl_msg);

    // state-transition logic and calculate next-state.
    switch (state)
    {
        case RESET:
            next_state = READY;
            break;
        case READY:
            if (new_ctrl_msg && (ctrl_msg == pwm_ctrl_msg_t::START))
                next_state = RUNNING;
            break;
        case RUNNING:
            if (schedule_failed)
                next_state = RESET;
            else if (scheduler.finished() ||
                    ((new_ctrl_msg) && (ctrl_msg == pwm_ctrl_msg_t::STOP)))
                next_state = READY;
            break;
        default:
            break;
    }

    // Handle output logic based on curr state or state transition.
    switch (state)
    {
        case RESET:
            schedule_failed = false;
            scheduler.reset();
            break;
        case READY:
            sync_schedule();
            if (next_state == RUNNING)
            {
                // Tell core0 we started.
                core1_next_state_msg_t msg{next_state, time_us_64_unsafe()};
                scheduler.start(); // Start ASAP to maximize timestamp accuracy.
                queue_try_add(&core1_next_state_queue, &msg);
            }
            break;
        case RUNNING:
            scheduler.update();
            if (next_state == READY)
                scheduler.stop(); // Must call stop to re-setup all tasks.
            if ((next_state == RESET) || (next_state == READY))
            {
                // Tell core0 we stopped or got reset.
                core1_next_state_msg_t msg{next_state, time_us_64_unsafe()};
                queue_try_add(&core1_next_state_queue, &msg);
            }
            break;
    }

    // Update state.
    state = next_state;
}


// Core1 main.
void __not_in_flash_func(core1_main)()
{
    state = core1_state_t::RESET;
    while (true)
        run_task_loop();
}

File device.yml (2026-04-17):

%YAML 1.1
---
# yaml-language-server: $schema=https://harp-tech.org/draft-02/schema/device.json
device: Cuttlefish
whoAmI: 1403
firmwareVersion: "0.1"
hardwareTargets: "0.0"
registers:
  PinDirection: &IORegister
    address: 32
    type: U8
    access: Write
    maskType: Pins
    description: "Set the direction of the pins. 0 = input; 1 = output"
  PinState:
    <<: *IORegister
    address: 33
    description: "Read or write the state of the pins."
  PinSet:
    <<: *IORegister
    address: 34
    description: "Set pins specified in the mask to logic HIGH by setting the
                 corresponding bit."
  PinClear:
    <<: *IORegister
    address: 35
    description: "Set specified pins in the mask to logic LOW by setting the
                  corresponding bit."
  EnableRisingEdgeEvents:
    <<: *IORegister
    address: 36
    description: "Enable Events from the RisingEdgeEvents register for the
                  specified pins in the mask when any of the the corresponding
                  pins transitions from logic LOW to logic HIGH."
  RisingEdgeEvents:
    <<: *IORegister
    address: 37
    access: Event
    description: "Event Only. Returns a timestamped message with the Port state
                  when any of the pins specified in the EnableRisingEdgeEvents
                  register transitions from logic LOW to logic HIGH."
  EnableFallingEdgeEvents:
    <<: *IORegister
    address: 38
    description: "Enable Events from the FallingEdgeEvents register for the
                  specified pins in the mask when any of the the corresponding
                  pins transitions from logic HIGH to logic LOW."
  FallingEdgeEvents:
    <<: *IORegister
    address: 39
    access: Event
    description: "Event Only. Returns a timestamped message with the Port state
                  when any of the pins specified in the EnableRisingEdgeEvents
                  register transitions from logic HIGH to logic LOW."
  PwmState:
    address: 40
    access: [Write, Event]
    type: U8
    maskType: EnableFlag
    description: "Write a nonzero value to this register to start the PWM
                  schedule. Write zero to stop the schedule. Receive an
                  event with payload=0 when the pwm schedule has finished."
  PwmSettings0: &PwmSettingsRegister
    address: 41
    type: U8
    access: Write
    length: 17
    description: "Struct to configure PWM0 settings:
                  offset_us (U32), on_duration_us (U32), off_duration_us (U32),
                  cycles (U32), invert (U8)"
  PwmSettings1:
    <<: *PwmSettingsRegister
    address: 42
    description: "Struct to configure PWM1 settings:
                  offset_us (U32), on_duration_us (U32), off_duration_us (U32),
                  cycles (U32), invert (U8)"
  PwmSettings2:
    <<: *PwmSettingsRegister
    address: 43
    description: "Struct to configure PWM2 settings:
                  offset_us (U32), on_duration_us (U32), off_duration_us (U32),
                  cycles (U32), invert (U8)"
  PwmSettings3:
    <<: *PwmSettingsRegister
    address: 44
    description: "Struct to configure PWM3 settings:
                  offset_us (U32), on_duration_us (U32), off_duration_us (U32),
                  cycles (U32), invert (U8)"
  PwmSettings4:
    <<: *PwmSettingsRegister
    address: 45
    description: "Struct to configure PWM4 settings:
                  offset_us (U32), on_duration_us (U32), off_duration_us (U32),
                  cycles (U32), invert (U8)"
  PwmSettings5:
    <<: *PwmSettingsRegister
    address: 46
    description: "Struct to configure PWM5 settings:
                  offset_us (U32), on_duration_us (U32), off_duration_us (U32),
                  cycles (U32), invert (U8)"
  PwmSettings6:
    <<: *PwmSettingsRegister
    address: 47
    description: "Struct to configure PWM6 settings:
                  offset_us (U32), on_duration_us (U32), off_duration_us (U32),
                  cycles (U32), invert (U8)"
  PwmSettings7:
    <<: *PwmSettingsRegister
    address: 48
    description: "Struct to configure PWM7 settings:
                  offset_us (U32), on_duration_us (U32), off_duration_us (U32),
                  cycles (U32), invert (U8)"

bitMasks:
  Pins:
    description: "Available pins on the device"
    bits:
      None: 0x0
      Pin0: 0x1
      Pin1: 0x2
      Pin2: 0x4
      Pin3: 0x8
      Pin4: 0x10
      Pin5: 0x20
      Pin6: 0x40
      Pin7: 0x80

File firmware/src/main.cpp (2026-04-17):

#include <pico/stdlib.h>
#include <cstring>
#include <config.h>
#include <harp_c_app.h>
#include <harp_synchronizer.h>
#include <cuttlefish_app.h>
#include <edge_event_queue.h>
#include <schedule_ctrl_queues.h>
#include <pico/multicore.h>
#include <hardware/structs/bus_ctrl.h>
#include <core1_main.h>

queue_t pwm_settings_queue;
// Keep timing critical core0 to ISR data structures in RAM.
__not_in_flash("edge_event_queue") queue_t edge_event_queue;
// Keep timing critical core-to-core communication data structures in RAM.
__not_in_flash("core1_ctrl_queue") queue_t core1_ctrl_queue;
__not_in_flash("core1_next_state_queue") queue_t core1_next_state_queue;
__not_in_flash("schedule_error_queue") queue_t schedule_error_queue;

// Create Core.
HarpCApp& app = HarpCApp::init(HARP_DEVICE_ID,
                               HW_VERSION_MAJOR, HW_VERSION_MINOR,
                               HW_ASSEMBLY_VERSION,
                               FW_VERSION_MAJOR, FW_VERSION_MINOR,
                               UNUSED_SERIAL_NUMBER, "Cuttlefish",
                               (uint8_t*)GIT_HASH,
                               app_reg_specs, APP_REG_COUNT, update_app_state,
                               reset_app);

// Core0 main.
int main()
{
    // Init Synchronizer.
    HarpSynchronizer::init(SYNC_UART, HARP_SYNC_RX_PIN);
    app.set_synchronizer(&HarpSynchronizer::instance());
    // Configure core1 to have high priority on the bus.
    bus_ctrl_hw->priority = 0x00000010;
    // Initialize queue for edge event message handling
    queue_init(&edge_event_queue, sizeof(EdgeEvent), 32);
    // Initialize queues for multicore communication.
    queue_init(&core1_ctrl_queue, sizeof(pwm_ctrl_msg_t), 8);
    queue_init(&core1_next_state_queue, sizeof(core1_next_state_msg_t), 8);
    queue_init(&pwm_settings_queue, sizeof(pwm_specs_core_msg_t), 32);
    queue_init(&schedule_error_queue, sizeof(uint8_t), 2);
#if defined(DEBUG) || defined(PROFILE_CPU)
#warning "Initializing printf from UART will slow down core1 main loop."
    stdio_uart_init_full(DEBUG_UART, 921600, DEBUG_UART_TX_PIN, -1);
#endif
    multicore_reset_core1();
    (void)multicore_fifo_pop_blocking(); // Wait until core1 is ready.
    multicore_launch_core1(core1_main);
    reset_app(); // Setup GPIO states. Get scheduler ready.
    // Loop forever.
    while(true)
        app.run();
}

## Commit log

2026-04-17 Feat mvp (#41)
    * strip down; get gpio working
    * update readme with waveform pic
    * draft pin change interrupt events
    * get rising edge events working via interrupt
    * split edge event status into separate register
    * update cross-core communication
    * drain gpio port events from queue; add test
    * update example
    * fix: emplace_front
    * fix pwm task reset behavior with output asserted
    * fix pwm task offset and iterations
    * remove overclocking
    * add suppressed copy-to-ram option in test; performance boost when unsuppressed
    * update device.yaml
    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
    [bus_selection.kicad_sch, cuttlefish.kicad_pcb, cuttlefish.kicad_sch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]
2026-10-28 Feat new pico core (#45)
    * update firmware to new pico core
    * update python examples
    * update hardware version in config
    * Update package with python interface and heterogenous registers (#46)
    * Refactor package to updated layout
    * Add python package metadata
    * Update device.yml and add examples
    * Refactor device interface and examples to use the new cuttlefish module
    * Fix namespace
    * Linting
    * Example for events does not work
    ---------
2026-10-31 Use a interfaceType to generate a reference to the PwmSettingsPayload (#49)
